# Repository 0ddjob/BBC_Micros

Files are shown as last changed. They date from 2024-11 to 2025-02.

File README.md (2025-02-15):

# BBC Micros
 Projects for the BBC Model A/B and Master.

## [Master Compact Floppy Interface](/Master_Compact_FDC_Interface)
Simple adaptor board to convert the DB25 floppy interface to a standard IDC 34-way header.
### Status: TESTED
- 17-Nov-2024: test PCBs ordered from PCBWAY
- 20-Nov-2024: PCBs shipped
- 27-Nov-2024: PCBs arrived
- 3-Dec-2024: tested successfully
<br>

```
DB25             34-IDC
                  2  1
        /INUSE    4--3 
                  6  5
    1---INDEX-----8  7
14  2---/DS0-----10  9
15  3---/DS1-----12 11
16  4---/DS2-----14 13
17  5---/MOTOR---16 15
18  6---/DIR-----18 17
19  7---/SEEK----20 19
20  8---/DATA----22 21
21  9---/ENABLE--24 23
22 10---/TRK0----26 25
23 11---/WRPROT--28 27
24 12---/READ----30 29
25 13---/SIDE----32 31
                 34 33

Pins 14-25 on DB25 connected to GND.
Odd pins on IDC connected to GND.
The Master Compact's original floppy cable has IDC pins 3 & 4 connected,
i.e. /INUSE grounded.  This doesn't seem to matter when using the Gotek.
```

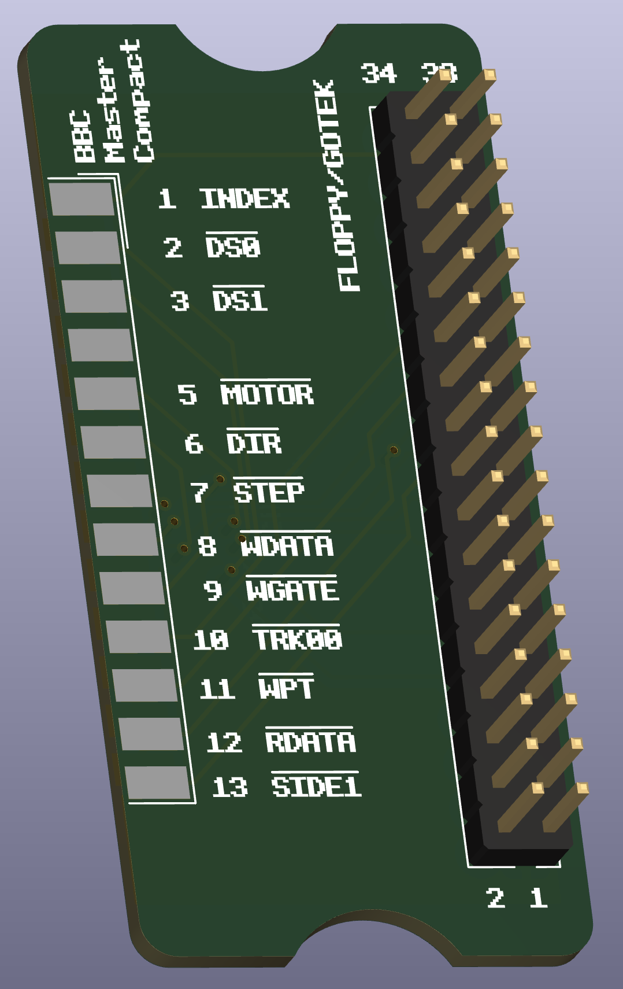
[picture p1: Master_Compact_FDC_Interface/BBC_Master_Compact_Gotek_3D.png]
3D render of board


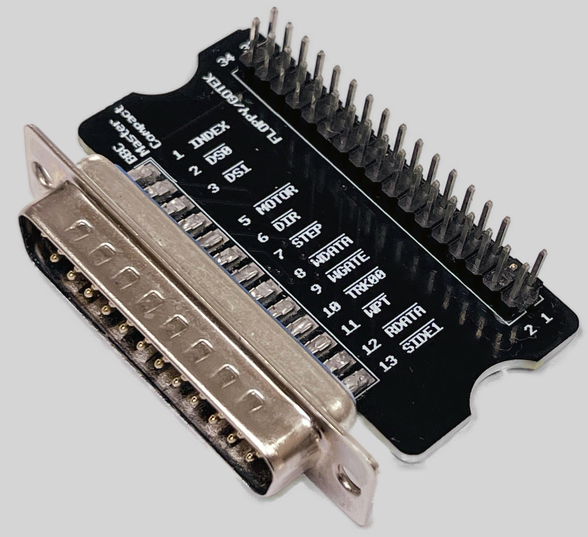
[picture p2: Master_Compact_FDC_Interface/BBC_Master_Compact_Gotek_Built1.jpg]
Built board

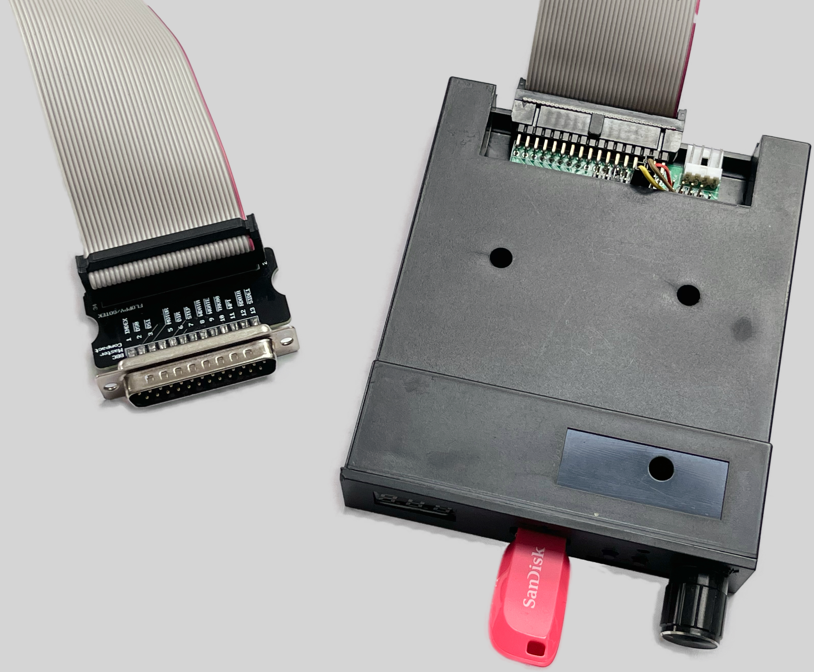
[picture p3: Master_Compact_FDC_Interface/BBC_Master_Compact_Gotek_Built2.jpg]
Built board with Gotek


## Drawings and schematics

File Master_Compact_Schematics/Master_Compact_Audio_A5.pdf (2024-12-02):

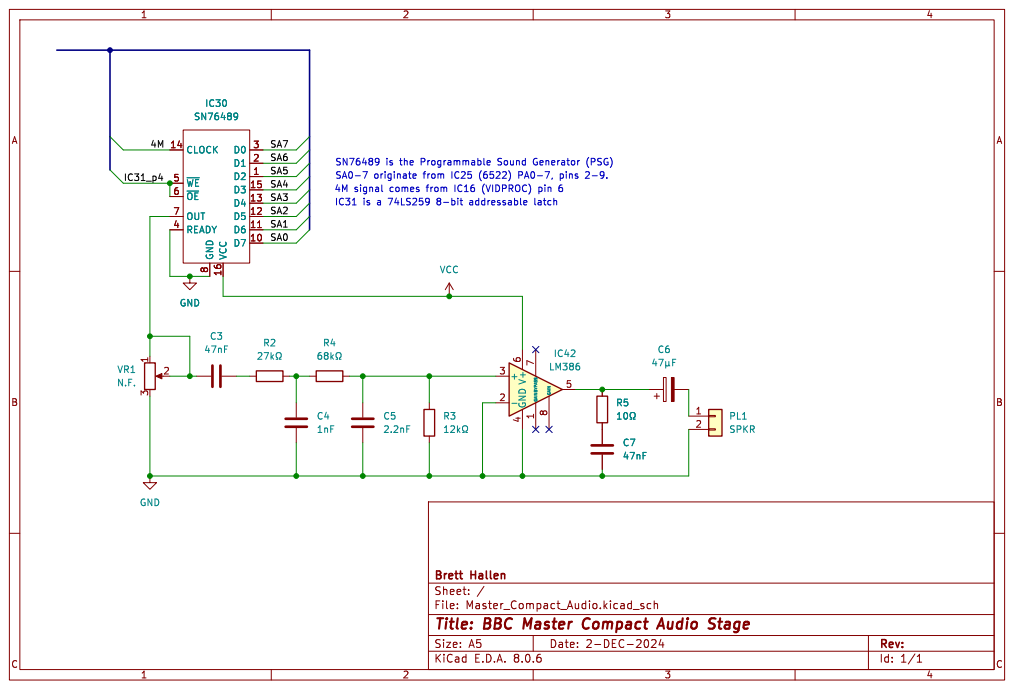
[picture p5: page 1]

Sheet: /
Title: BBC Master Compact Audio Stage

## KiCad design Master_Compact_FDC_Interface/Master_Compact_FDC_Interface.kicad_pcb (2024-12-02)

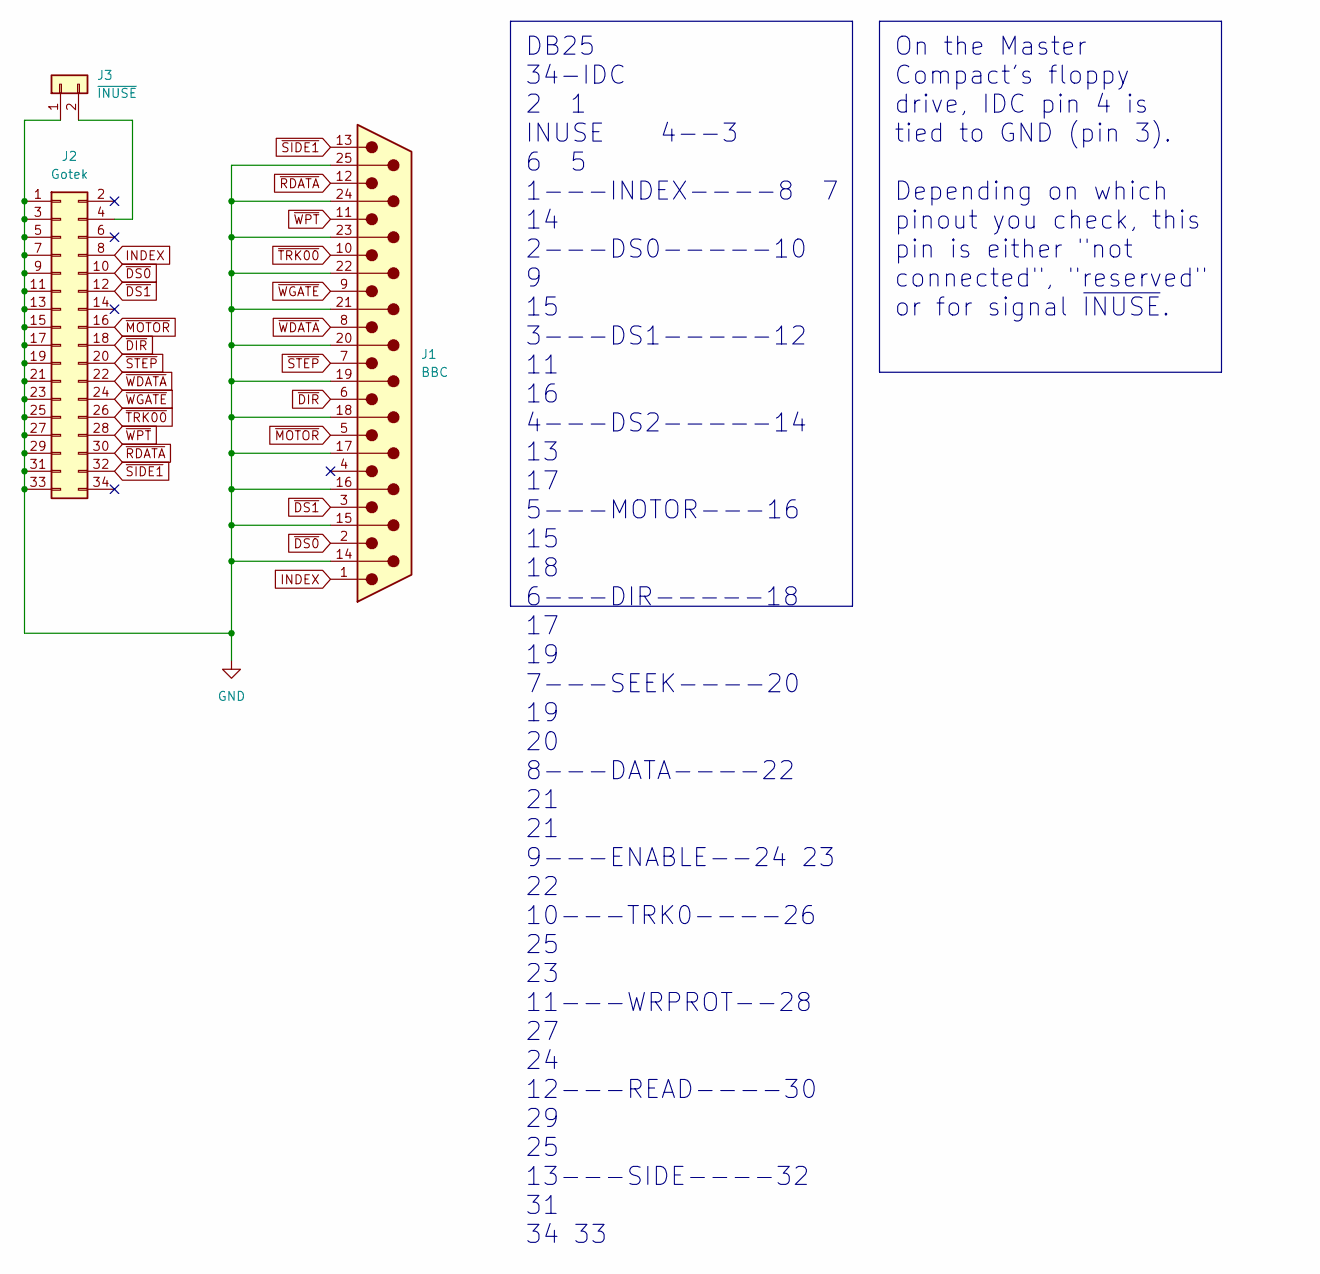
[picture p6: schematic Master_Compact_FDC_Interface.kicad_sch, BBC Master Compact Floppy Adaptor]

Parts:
J1: BBC; DSUB-25_Male_EdgeMount_P2.77mm
J2: Gotek; PinHeader_2x17_P2.54mm_Vertical
J3: ~{INUSE}; PinHeader_1x02_P2.54mm_Vertical

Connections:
GND: J1.14, J1.15, J1.16, J1.17, J1.18, J1.19, J1.20, J1.21, J1.22, J1.23, J1.24, J1.25, J2.1, J2.3, J2.5, J2.7, J2.9, J2.11, J2.13, J2.15, J2.17, J2.19, J2.21, J2.23, J2.25, J2.27, J2.29, J2.31, J2.33, J3.1
INDEX: J1.1, J2.8
unnamed: J2.4, J3.2
~DIR: J1.6, J2.18
~DS0: J1.2, J2.10
~DS1: J1.3, J2.12
~MOTOR: J1.5, J2.16
~RDATA: J1.12, J2.30
~SIDE1: J1.13, J2.32
~STEP: J1.7, J2.20
~TRK00: J1.10, J2.26
~WDATA: J1.8, J2.22
~WGATE: J1.9, J2.24
~WPT: J1.11, J2.28

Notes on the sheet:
On the Master Compact's floppy drive, IDC pin 4 is tied to GND (pin 3). Depending on which pinout you check, this pin is either "not connected", "reserved" or for signal ~{INUSE}.
DB25 34-IDC 2 1 INUSE 4--3 6 5 1---INDEX----8 7 14 2---DS0-----10 9 15 3---DS1-----12 11 16 4---DS2-----14 13 17 5---MOTOR---16 15 18 6---DIR-----18 17 19 7---SEEK----20 19 20 8---DATA----22 21 21 9---ENABLE--24 23 22 10---TRK0----26 25 23 11---WRPROT--28 27 24 12---READ----30 29 25 13---SIDE----32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

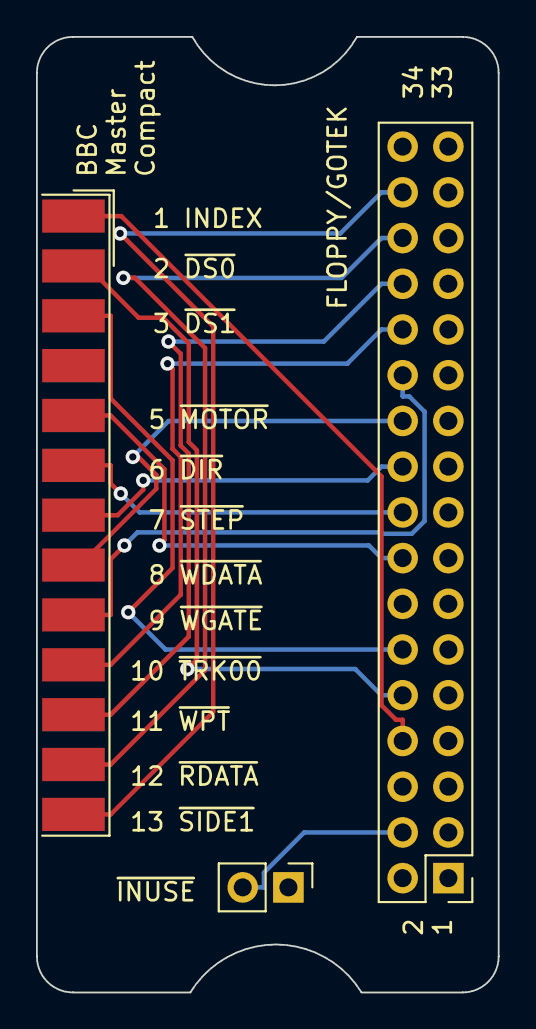
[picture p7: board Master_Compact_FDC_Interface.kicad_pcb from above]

Board: 2 copper layers, 25.7 x 53.1 mm, 3 parts (0 on the bottom side), 14 nets.

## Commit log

2024-11-16 Renamed Gerbers file
2024-11-17 Reversed IDC header
    [Master_Compact_FDC_Interface.kicad_pcb, Master_Compact_FDC_Interface.kicad_sch]
2024-12-02 Added "schematic scraps" section
    [Master_Compact_Audio.kicad_pcb, Master_Compact_Audio.kicad_sch, Master_Compact_FDC_Interface.kicad_pcb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]
2024-12-03 Added Gotek ADFS files
    [FF.CFG, IMAGE_A.CFG]
